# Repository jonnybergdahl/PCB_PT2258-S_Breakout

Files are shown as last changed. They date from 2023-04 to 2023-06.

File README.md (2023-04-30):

# Audio_PT2258-S_Breakout

This is a breakout board for the Princeton Technoloy PT2258-S chip. 

According to the manufacturer:
> PT2258 is a 6-Channel Electronic Volume Controller IC utilizing CMOS Technology specially designed
for the new generation of AV Multi-Channel Audio System. PT2258 provides an I2
C Control Interface,
an attenuation range of 0 to -79dB at 1dB/step, low noise, and high channel separation.

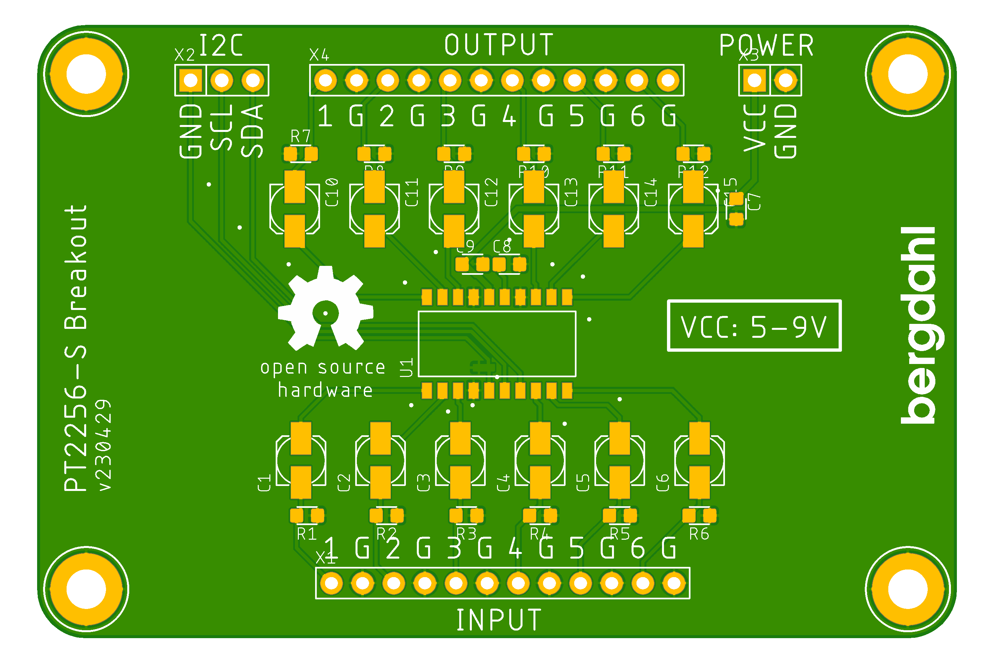
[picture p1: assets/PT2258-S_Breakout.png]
Image of PCB PCB


## I2C pins

Name | Description
---- | ----
GND | Ground
SCL | Serial clock line
SDA | Serial data line

## Inputs
Name | Description
---- | ----
1 | Input 1
2 | Input 2
3 | Input 3
4 | Input 4
5 | Input 5
6 | Input 6
GND | Ground (6 of them)

## Outputs
Name | Description
---- | ----
1 | Output 1
2 | Output 2
3 | Output 3
4 | Output 4
5 | Output 5
6 | Output 6
GND | Ground (6 of them)

## Power
Name | Description
---- | ----
VCC | 5-9V power
GND | Ground

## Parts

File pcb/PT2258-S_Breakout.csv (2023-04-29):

Qty | Value | Device | Package | Parts | Description
12 | 100K | RESISTOR0603 | R0603 | R1, R2, R3, R4, R5, R6, R7, R8, R9, R10, R11, R12
1 | 100nF | CAPC0603 | C0603 | C9
12 | 10uF | CAP-POL-ALUMROQANG-RVT0405 | ROQANG-RVT0405 | C1, C2, C3, C4, C5, C6, C10, C11, C12, C13, C14, C15
2 | 10uF | CAPC0603 | C0603 | C7, C8
1 | I2C | HEADER-1X03-2.54P | 1X03P-2.54 | X2
1 | INPUT | HEADER-1X12-2.54 | 1X12-2.54 | X1
4 | MOUNTHOLE-PAD3.2 | MOUNTHOLE-PAD3.2 | 3.2-PAD | H1, H2, H3, H4
1 | OUTPUT | HEADER-1X12-2.54 | 1X12-2.54 | X4
1 | POWER | HEADER-1X02-2.54POL | 1X02P-2.54 | X3
1 | PT2258-S | PT2258 | SOP-20 | U1
1 | SHORT-SMD-06096 | SHORT-SMD-06096 | SHORT-SMD-06096 | SH1

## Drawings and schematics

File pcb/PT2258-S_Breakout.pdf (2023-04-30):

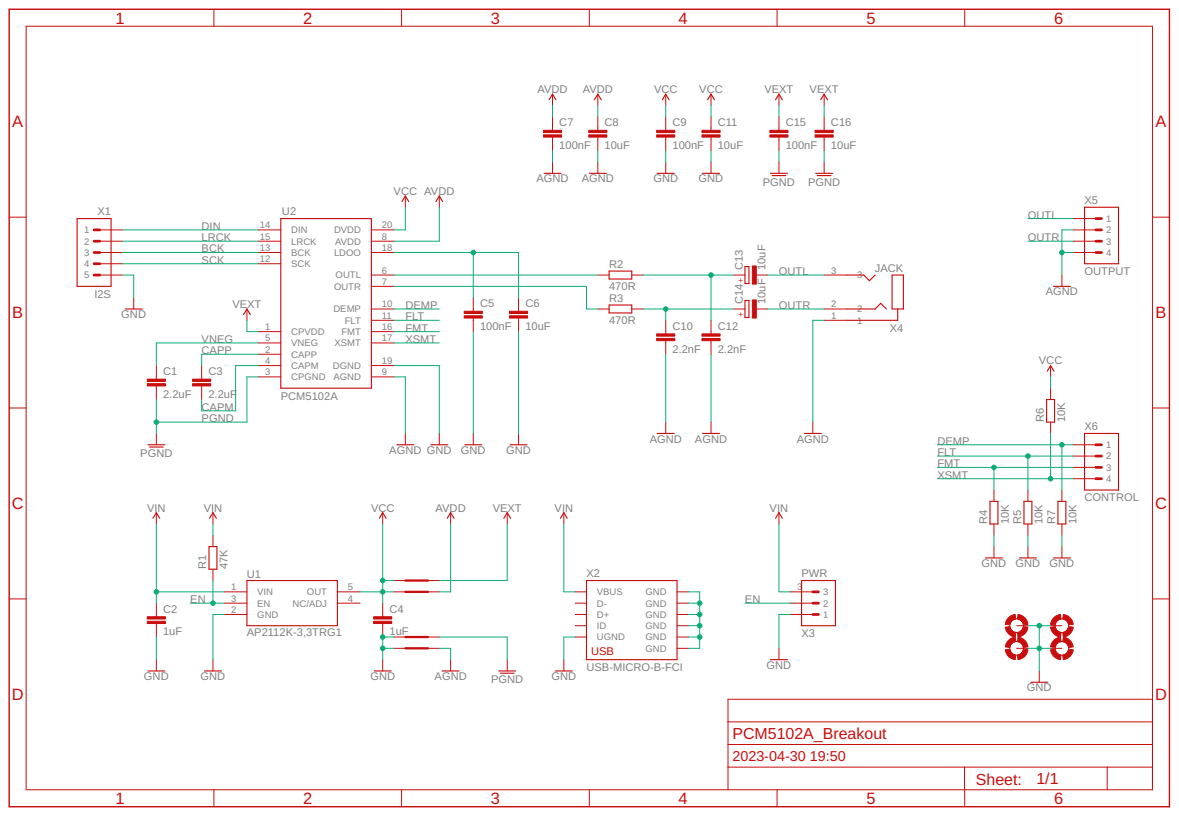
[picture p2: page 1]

6 OUTR

10 FLT DEMP

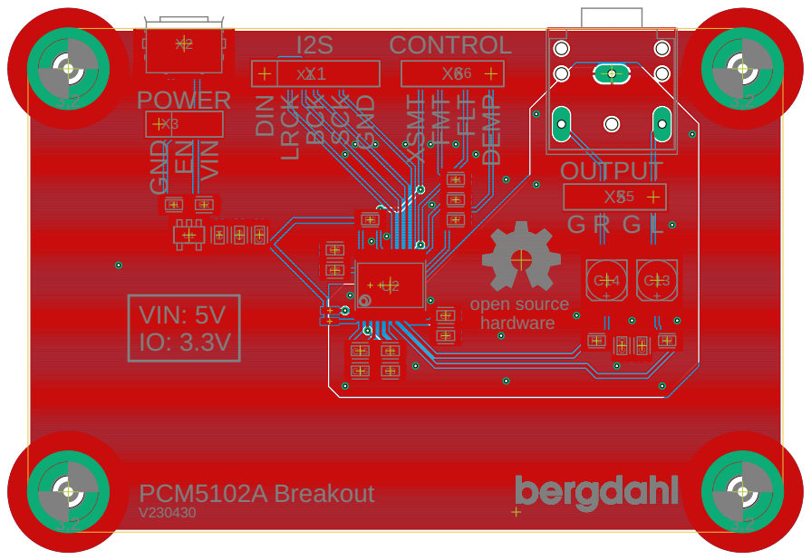
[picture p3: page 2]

open source

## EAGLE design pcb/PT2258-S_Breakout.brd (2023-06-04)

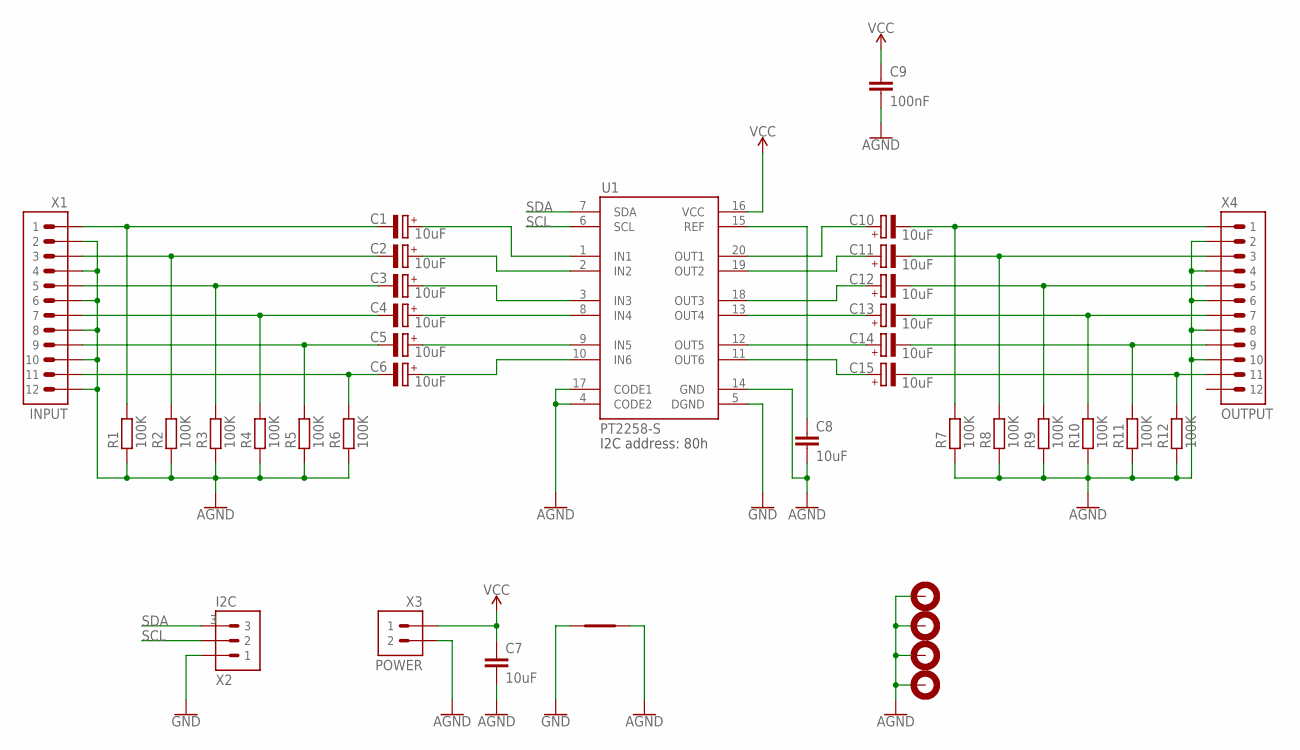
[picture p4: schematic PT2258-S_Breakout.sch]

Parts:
C1, C2, C3, C4, C5, C6, C10, C11, C12, C13, C14, C15: 10uF; ROQANG-RVT0405
C7, C8: 10uF; C0603
C9: 100nF; C0603
H1, H2, H3, H4: MOUNTHOLE-PAD3.2; 3.2-PAD
R1, R2, R3, R4, R5, R6, R7, R8, R9, R10, R11, R12: 100K; R0603
SH1: SHORT-SMD-06096
U1: PT2258-S; SOP-20-300
X1: INPUT; 1X12-2.54
X2: I2C; 1X03P-2.54
X3: POWER; 1X02P-2.54
X4: OUTPUT; 1X12-2.54

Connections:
AGND: C7.2, C8.2, C9.2, H1.B3,2, H2.B3,2, H3.B3,2, H4.B3,2, R1.1, R2.1, R3.1, R4.1, R5.1, R6.1, R7.1, R8.1, R9.1, R10.1, R11.1, R12.1, SH1.2, U1.4 (CODE2), U1.14 (GND), U1.17 (CODE1), X1.2, X1.4, X1.6, X1.8, X1.10, X1.12, X3.2, X4.2, X4.4, X4.6, X4.8, X4.10
GND: SH1.1, U1.5 (DGND), X2.1
unnamed: C10.-, R7.2, X4.1
unnamed: C11.-, R8.2, X4.3
unnamed: C12.-, R9.2, X4.5
unnamed: C13.-, R10.2, X4.7
unnamed: C14.-, R11.2, X4.9
unnamed: C15.-, R12.2, X4.11
unnamed: C4.+, U1.8 (IN4)
unnamed: C1.+, U1.1 (IN1)
unnamed: C15.+, U1.11 (OUT6)
unnamed: C14.+, U1.12 (OUT5)
unnamed: C13.+, U1.13 (OUT4)
unnamed: C12.+, U1.18 (OUT3)
unnamed: C11.+, U1.19 (OUT2)
unnamed: C10.+, U1.20 (OUT1)
unnamed: C8.1, U1.15 (REF)
unnamed: C2.+, U1.2 (IN2)
unnamed: C3.+, U1.3 (IN3)
unnamed: C5.+, U1.9 (IN5)
unnamed: C6.+, U1.10 (IN6)
unnamed: C1.-, R1.2, X1.1
unnamed: C2.-, R2.2, X1.3
unnamed: C3.-, R3.2, X1.5
unnamed: C4.-, R4.2, X1.7
unnamed: C5.-, R5.2, X1.9
unnamed: C6.-, R6.2, X1.11
SCL: U1.6 (SCL), X2.2
SDA: U1.7 (SDA), X2.3
VCC: C7.1, C9.1, U1.16 (VCC), X3.1

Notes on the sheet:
I2C address: 80h

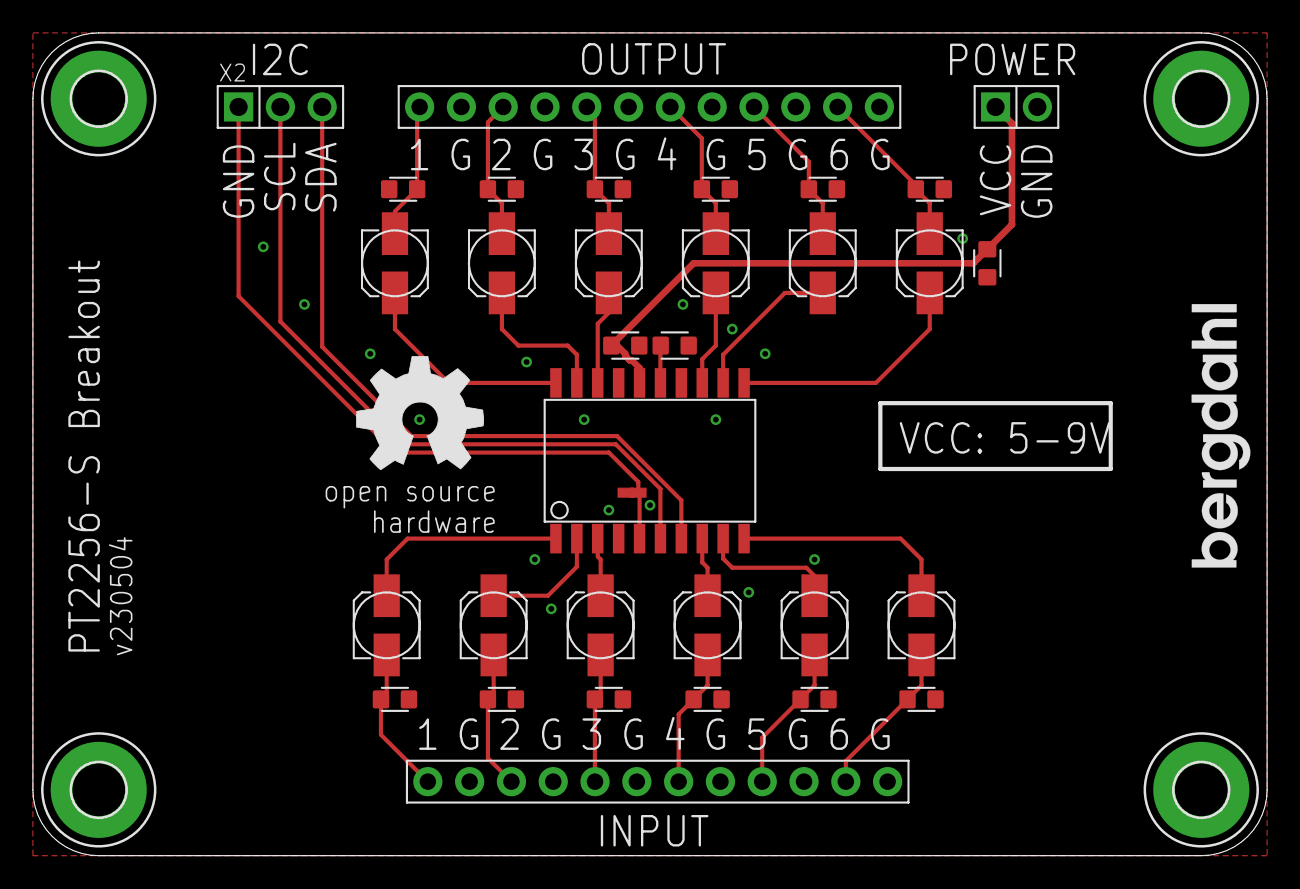
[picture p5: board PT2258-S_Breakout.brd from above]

Board: 2 copper layers, 75.0 x 50.0 mm, 41 parts (0 on the bottom side), 30 nets.

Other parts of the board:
U$1: BERGDAHL-20MM-BPLACE
U$2: OSHW-8MM-BPLACE
U$3: BERGDAHL-20MM-TPLACE
U$5: OSHW-8MM-TPLACE

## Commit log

2023-04-30 Final version
    [PT2258-S_Breakout.GBL, PT2258-S_Breakout.GBO, PT2258-S_Breakout.GBP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]
2023-04-30 Update PDF
    [PT2258-S_Breakout.brd]
2023-06-04 Fix SOP-20-300 footprint
    [PT2258-S_Breakout.brd, PT2258-S_Breakout.sch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]
